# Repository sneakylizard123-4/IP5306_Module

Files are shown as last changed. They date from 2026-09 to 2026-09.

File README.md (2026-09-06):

# IP5306 Power-Bank Module

A small USB power bank module that uses a 1S lithium battery and outputs a regulated 5V supply.

This board is a small power bank module built around the Injoinic IP5306 SoC. It takes USB-C input to charge a lithium battery and outputs a regulated 5V rail from a USB-A port in output mode. It is a standalone module with no MCU, only a power button and 4-LED charge/fuel gauge handle all user input. I built it to have a fully integrated power path solution that avoids the complexity of discrete charger and boost circuits.

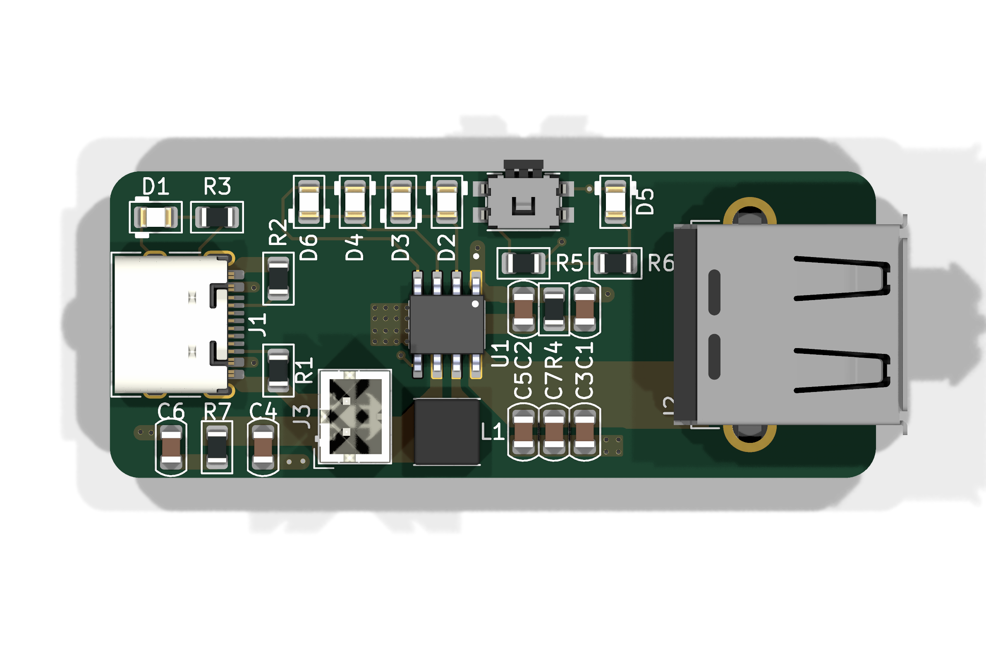
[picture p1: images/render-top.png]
3D model render


## Features

- IP5306: fully integrated 2.1A charger and 2.4A discharger with built-in boost converter.
- USB-C input for charging, USB-A output for 5V output.
- 1S Li-ion/LiPo battery connection via JST PH 2-pin header.
- Power button for power on/off and battery gauge.
- 4-LED charge/fuel gauge.
- 1uH shielded inductor for the boost converter.

## How It Works

The IP5306 has an entire power path inside of it. On the input side, 5v from USB-C charges a connected 1S lithium battery through the IP5306's built-in 2.1A charger. On the output side, the chip boosts the battery voltage to a regulated 5V output rail when in power-bank mode. The boost inductor and output capacitors form the boost converter, while the battery, LED, and decoupling capacitors support the charge path, gauge, and IC supply. Pressing the KEY button powers the module on/off and goes through the fuel gauge.

| Block | Part | Role |
|---|---|---|
| Power | IP5306 | Power Bank SoC with battery charger, boost regulator, 5V rail, charge gauge |
| Input | HRO TYPE-C-31-M-12 | USB-C receptacle for charging input |
| Output | Connfly DS1095 | USB-A receptacle for 5V power-bank output |
| Battery | B2B-PH-K | JST PH 2-pin connector to 1S Li-ion/LiPo battery |
| Inductor | Coilcraft XFL4020-102MEC | 1uH boost converter inductor |
| Capacitors | 10uF x4, 22uF x3  Boost output + IC decoupling |
| Resistors | 5.1k x2, 10k x3, 2 ohm x2 | USB-C CC pulldowns, biasing, LED current limit |
| LEDs | 0805 x6 | Charge and boost status indicators |
| Button | Panasonic EVQPUM | Power on/off + fuel gauge on KEY pin |

### Power Tree

The power path flows from the USB-C input through the IP5306 charger into the battery, and from the battery through the IP5306 boost converter out to the USB-A port. The KEY button and LED gauge hang off the chip's control pins.

| Direction | Path |
|---|---|
| Charge | USB-C (5V) -> IP5306 charger -> 1S battery |
| Discharge | 1S battery -> IP5306 boost -> 5V USB-A out |

## Board

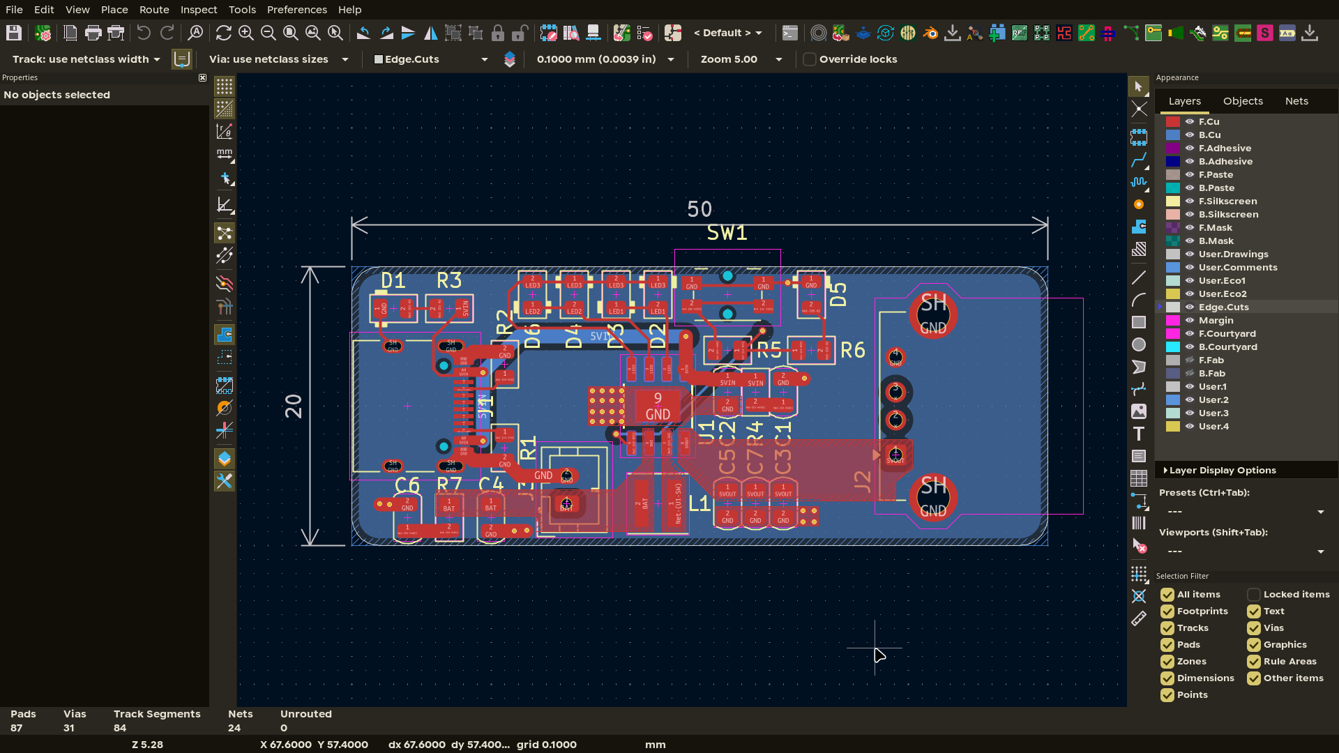
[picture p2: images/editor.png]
IP5306 module open in the KiCad PCB editor


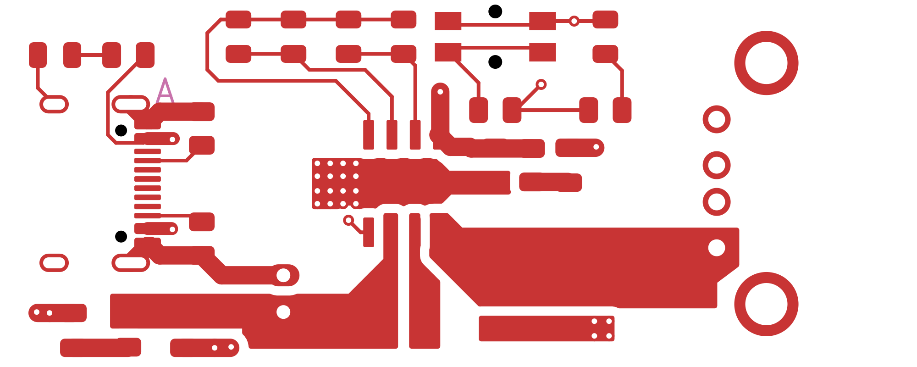
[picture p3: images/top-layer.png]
Top copper layer

*Top layer with the tracks, pads and ground pour.*

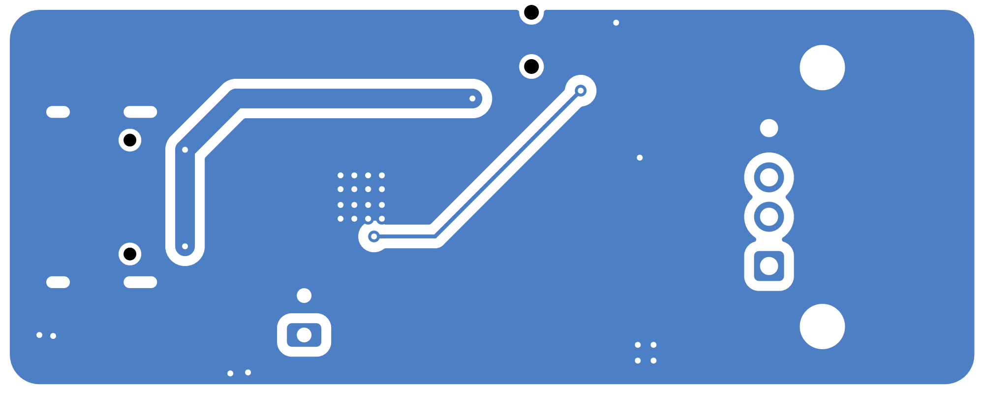
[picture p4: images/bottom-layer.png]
Bottom copper layer

*Bottom layer with the stitched ground return path.*

Assembled board, top view

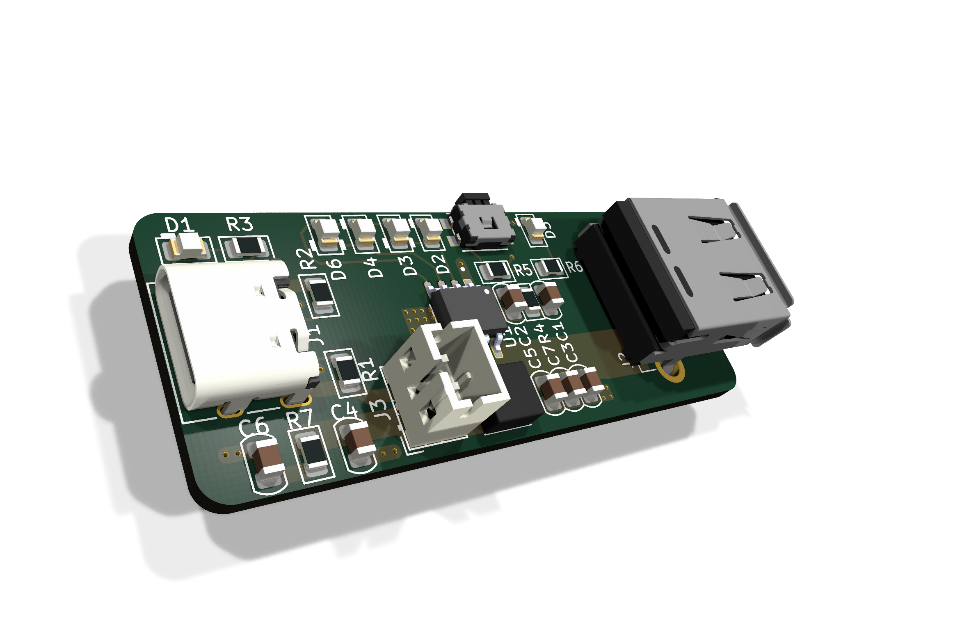
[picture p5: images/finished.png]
Assembled board, isometric view


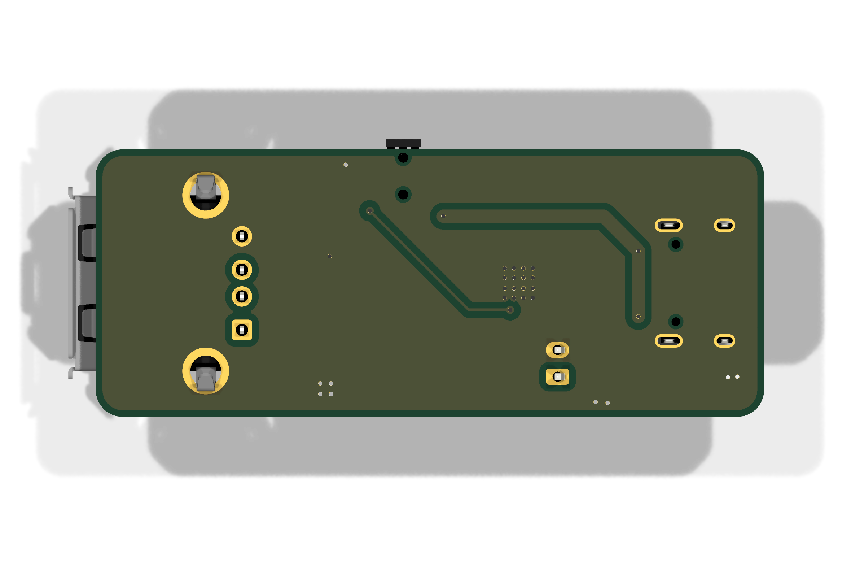
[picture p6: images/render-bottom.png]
Assembled board, bottom view


## Usage

1. Connect a 3.7V Li-ion/LiPo battery to the JST PH connector. 
2. Connect the USB-C to charge the battery. the LEDs indicate charge state. 
3. Connect a device to the USB-A port and press the power button to enable the 5V output; short presses cycle the LED fuel gauge and a long press toggles the module on/off.

| Pin | Function |
|-----|---|
| BAT+ / BAT- | JST PH battery connections (1S Li-ion/LiPo) |
| KEY | Power button input |
| GND | Common ground |

## Repository Structure

```
├── kicad/            # PCB source files
│   └── production/   # Gerbers + drill files
├── cad/              # .step export + native CAD source
├── firmware/         # Firmware source code
├── images/           # Renders, PCB screenshots, build photos
├── BOM.csv           # Bill of materials w/ links + total cost line
└── JOURNAL.md        # Work journal
```

## Cost

| Item | Cost |
|---|---|
| PCB | $3.20 |
| Shipping | $1.50 |
| **PCB subtotal** | **$4.70** |
| Components | $12.99 |
| **Total** | **$17.69** |

*Full BOM available in BOM.csv*

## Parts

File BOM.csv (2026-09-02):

Ref | Value | LCSC# | MPN | Manufacturer | Footprint | Qty | Unit Price($) | Ext Price($) | Supplier Link
C1 | C2 | C4 | C6 | 10uF 25V X5R | C15850 | CL21A106KAYNNNE | Samsung Electro-Mechanics | 0805 | 20 | 0.0871 | 1.74 | https://www.lcsc.com/product-detail/C15850.html
C3 | C5 | C7 | 22uF 25V X5R | C86816 | GRM21BR61E226ME44L | muRata | 0805 | 10 | 0.0698 | 0.70 | https://www.lcsc.com/product-detail/C86816.html
D1 | D2 | D3 | D4 | D5 | D6 | Orange LED 0805 | C965813 | XL-2012UOC | XINGLIGHT | 0805 | 50 | 0.0096 | 0.48 | https://www.lcsc.com/product-detail/C965813.html
J1 | USB-C Receptacle 16P | C165948 | TYPE-C-31-M-12 | Korean Hroparts Elec | SMD | 5 | 0.1724 | 0.86 | https://www.lcsc.com/product-detail/C165948.html
J2 | USB-A Right Angle | C19944603 | DS1095-WNR0 | CONNFLY Elec | Through Hole | 5 | 0.2076 | 1.04 | https://www.lcsc.com/product-detail/C19944603.html
J3 | JST PH 2P 2mm | C131337 | B2B-PH-K-S(LF)(SN) | JST | Through Hole | 20 | 0.0356 | 0.71 | https://www.lcsc.com/product-detail/C131337.html
L1 | 1uH Shielded Inductor | C5355380 | XFL4020-102MEC | Coilcraft | SMD 4x4mm | 1 | 2.5134 | 2.51 | https://www.lcsc.com/product-detail/C5355380.html
R1 | R2 | 5.1k 1% 0805 | C27834 | 0805W8F5101T5E | UNI-ROYAL | 0805 | 100 | 0.0065 | 0.65 | https://www.lcsc.com/product-detail/C27834.html
R3 | R5 | R6 | 10k 1% 0805 | C2907219 | FRC0805F1002TS | FOJAN | 0805 | 100 | 0.0035 | 0.35 | https://www.lcsc.com/product-detail/C2907219.html
R4 | R7 | 2R 1% 0805 | C114246 | RC0805FR-072RL | YAGEO | 0805 | 50 | 0.0261 | 1.31 | https://www.lcsc.com/product-detail/C114246.html
SW1 | Tactile Switch 4.7x4.5mm | C388885 | EVQPUD02K | PANASONIC | SMD | 5 | 0.2299 | 1.15 | https://www.lcsc.com/product-detail/C388885.html
U1 | IP5306 ESOP-8 | C181692 | IP5306 | INJOINIC | ESOP-8 | 5 | 0.2989 | 1.49 | https://www.lcsc.com/product-detail/C181692.html
PCB | Bare PCB 5 pcs (JLCPCB special offer) |  |  | JLCPCB |  | 5 | 0.64 | 3.20
Shipping |  | Global Standard (JLCPCB) |  |  |  | 1 | 1.50 | 1.50
Total |  |  | Components (LCSC) + PCB + shipping |  |  |  | 17.69

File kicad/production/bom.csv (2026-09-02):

Designator | Footprint | Quantity | Value | LCSC Part #
C1, C2, C4, C6 | 0805 | 4 | 10uF
C3, C5, C7 | 0805 | 3 | 22uF
D1, D2, D3, D4, D5, D6 | 0805 | 6 | LED
J1 | USB_C_Receptacle_HRO_TYPE-C-31-M-12 | 1 | USB_C_Receptacle_USB2.0_16P
J2 | USB_A_Connfly_DS1095 | 1 | USB_A
J3 | JST_PH_B2B-PH-K_1x02_P2.00mm_Vertical | 1 | Conn_01x02
L1 | L_Coilcraft_XxL4020 | 1 | 1uH XFL4020-102MEC
R1, R2 | 0805 | 2 | 5.1k
R3, R5, R6 | 0805 | 3 | 10k
R4, R7 | 0805 | 2 | 2
SW1 | Panasonic_EVQPUM_EVQPUD | 1 | SW_Push
U1 | SOP127P600X165-9N | 1 | IP5306

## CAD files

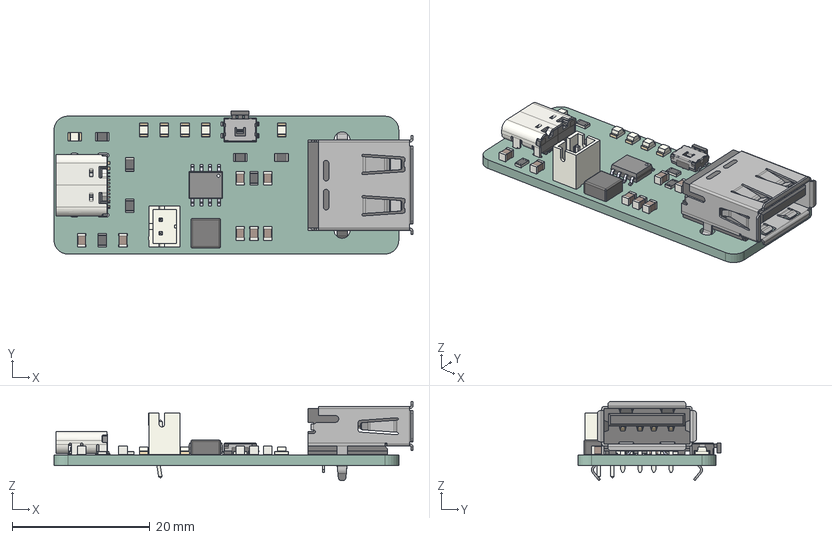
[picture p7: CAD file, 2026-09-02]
cad/IP5306_Module.step
52.1 x 20.8 x 11.5 mm
R_0805_2012Metric x 7
C_0805_2012Metric x 7
USB_A_Molex_67643_Horizontal
LED_0805_2012Metric x 6
L_Coilcraft_XAL4020-XXX
IP5306
JST_B2B_PH_K
Panasonic_EVQPUM_EVQPUD
USB_C_Receptacle_16P_TopMnt_Horizontal_GCT_USB4105-xx-A
IP5306_Module_PCB

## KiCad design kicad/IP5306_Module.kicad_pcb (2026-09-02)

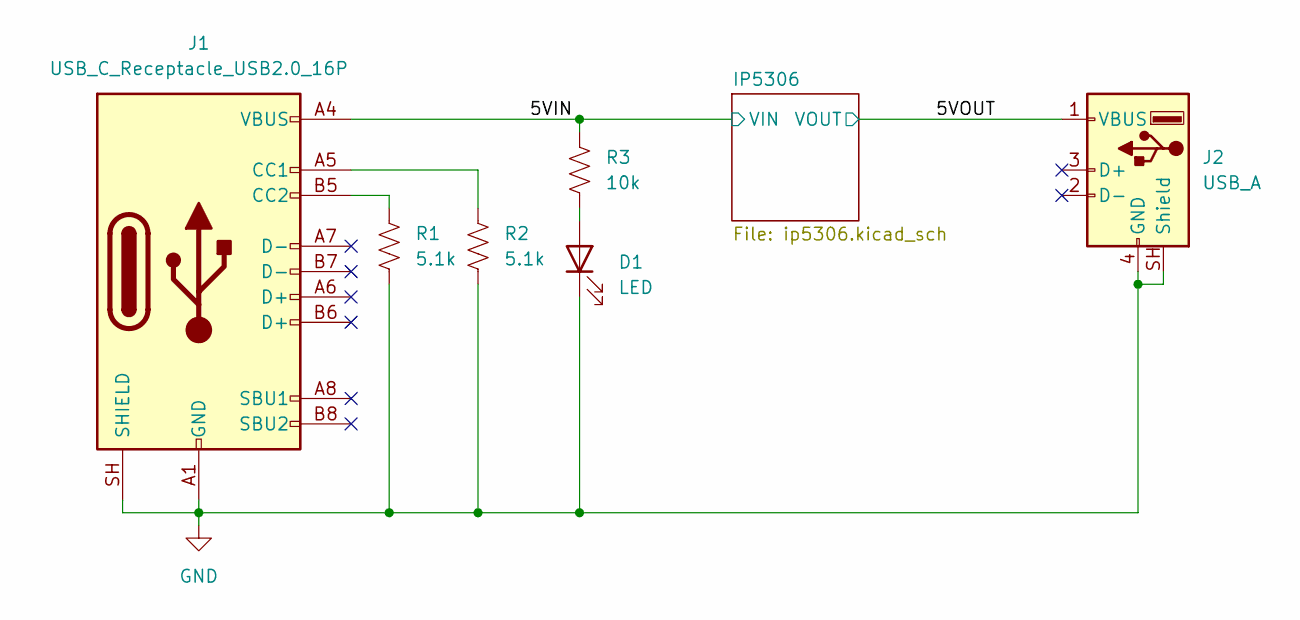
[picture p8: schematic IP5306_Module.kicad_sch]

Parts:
D1: LED; LED_0805_2012Metric
J1: USB_C_Receptacle_USB2.0_16P; USB_C_Receptacle_HRO_TYPE-C-31-M-12
J2: USB_A; USB_A_Connfly_DS1095
R1, R2: 5.1k; R_0805_2012Metric
R3: 10k; R_0805_2012Metric

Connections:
/5VIN: J1.A4 (VBUS), J1.A9 (VBUS), J1.B4 (VBUS), J1.B9 (VBUS), R3.1; also elsewhere on the board
/5VOUT: J2.1 (VBUS); also elsewhere on the board
GND: D1.1 (K), J1.A1 (GND), J1.A12 (GND), J1.B1 (GND), J1.B12 (GND), J1.SH (SHIELD), J2.4 (GND), J2.SH (Shield), R1.2, R2.2; also elsewhere on the board
unnamed: D1.2 (A), R3.2
unnamed: J1.A5 (CC1), R2.1
unnamed: J1.B5 (CC2), R1.1

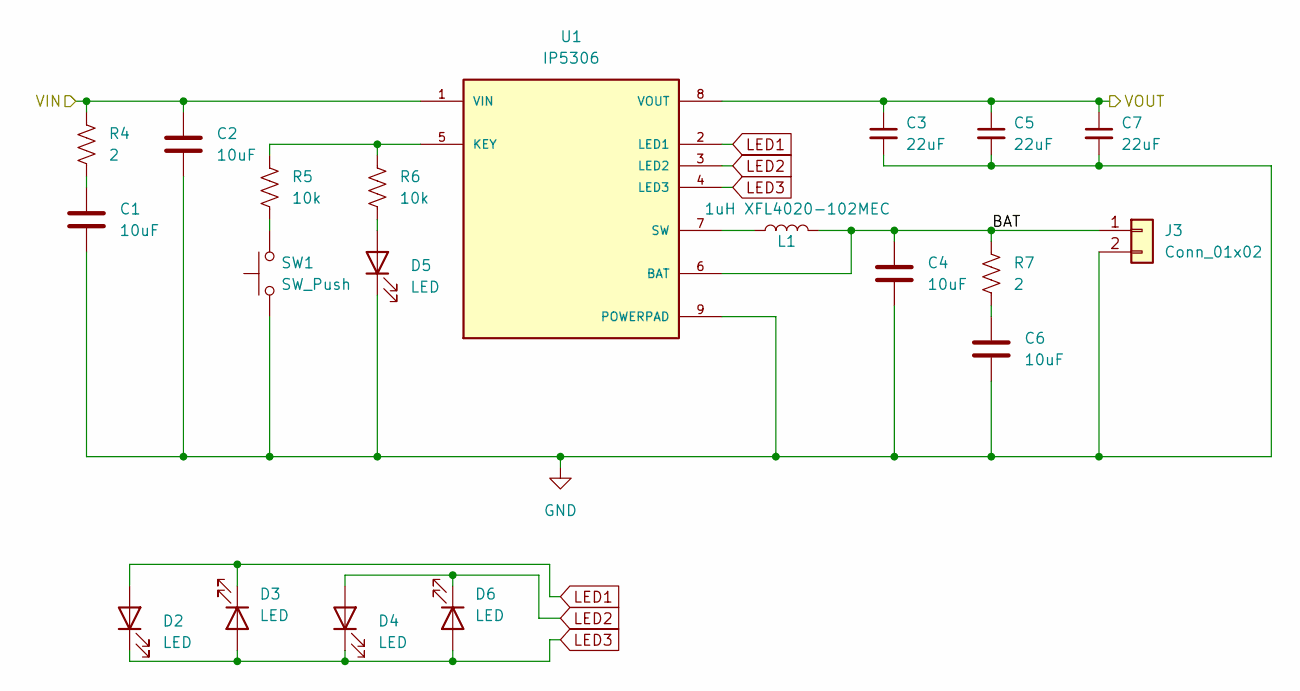
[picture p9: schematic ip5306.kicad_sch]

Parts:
C1, C2, C4, C6: 10uF; C_0805_2012Metric
C3, C5, C7: 22uF; C_0805_2012Metric
D2, D3, D4, D5, D6: LED; LED_0805_2012Metric
J3: Conn_01x02; JST_PH_B2B-PH-K_1x02_P2.00mm_Vertical
L1: 1uH XFL4020-102MEC; L_Coilcraft_XxL4020
R4, R7: 2; R_0805_2012Metric
R5, R6: 10k; R_0805_2012Metric
SW1: SW_Push; Panasonic_EVQPUM_EVQPUD
U1: IP5306; SOP127P600X165-9N; PARTREV 1.31

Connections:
/5VIN: C2.1, R4.1, U1.1 (VIN); also elsewhere on the board
/5VOUT: C3.1, C5.1, C7.1, U1.8 (VOUT); also elsewhere on the board
/IP5306/BAT: C4.1, J3.1, L1.2, R7.1, U1.6 (BAT)
GND: C1.2, C2.2, C3.2, C4.2, C5.2, C6.2, C7.2, D5.1 (K), J3.2, SW1.1, U1.9 (POWERPAD); also elsewhere on the board
LED1: D2.2 (A), D3.1 (K), U1.2 (LED1)
LED2: D4.2 (A), D6.1 (K), U1.3 (LED2)
LED3: D2.1 (K), D3.2 (A), D4.1 (K), D6.2 (A), U1.4 (LED3)
unnamed: C1.1, R4.2
unnamed: C6.1, R7.2
unnamed: D5.2 (A), R6.2
unnamed: R5.2, SW1.2
unnamed: R5.1, R6.1, U1.5 (KEY)
unnamed: L1.1, U1.7 (SW)

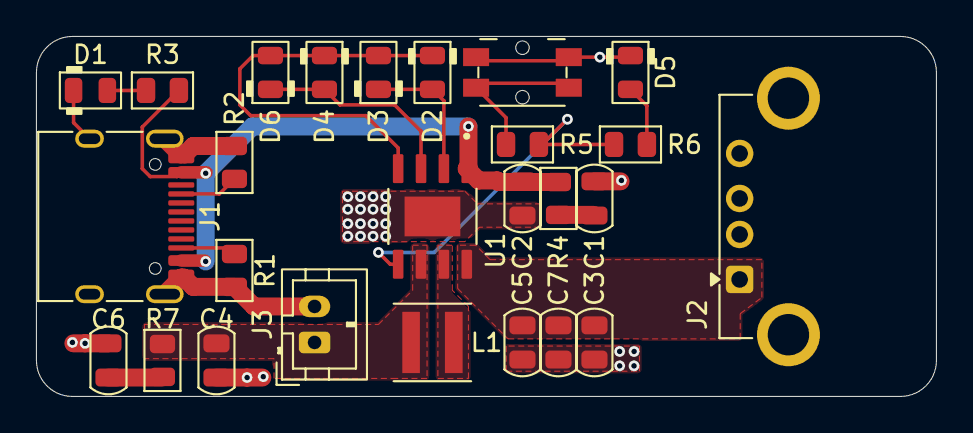
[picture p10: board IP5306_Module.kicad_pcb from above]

Board: 2 copper layers, 50.0 x 20.0 mm, 26 parts (0 on the bottom side), 16 nets.

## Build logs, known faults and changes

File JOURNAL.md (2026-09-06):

---
title: IP5306 Module
author: sneak
description: A super small 2-layer module that uses the IP5306 SoC, with USB-C charging input, USB-A 5V output, a battery connector, and LED indicators.
created_at: 2026-09-02
---

# 2026-09-02: Schematic capture

Started by pulling up the IP5306 datasheet. This little SoC does everything in one chip - it charges the lithium cell, boosts it back up to 5V for output, and even has its own LEDs for capacity and charging state, and those same led pins can also be used for I2C in some variants.

The core parts of the schematic were the IP5306 itself, a USB-C jack for input (charging), a USB-A jack for the 5V output, a JST connector for the battery, some LEDs, and the passives around the power path. I mainly copied the reference circuit from the datasheet, mostly because I trust it more than my own guesses for a power chip like this.

Biggest miss here: I did not connect the USB-C data pins (D+/D-) to anything, just left them floating with the CC pins handled via breakouts. The IP5306 is a dedicated power device, so it does not need data, but leaving them unconnected on the connector is a bit sloppy and I know some host chargers look for something there.

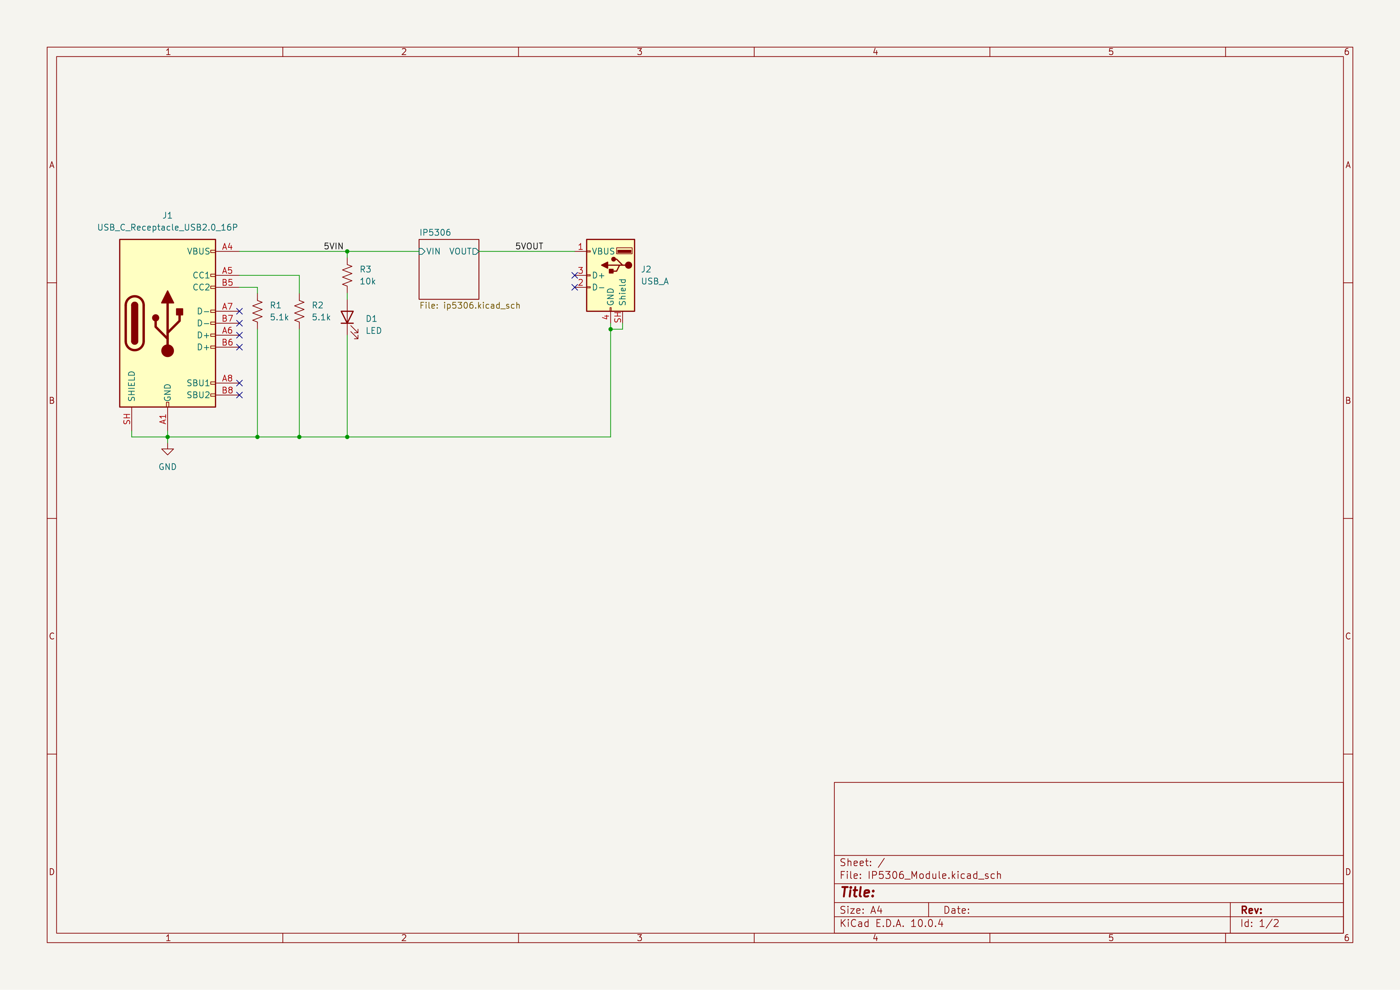
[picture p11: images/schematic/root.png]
schematic


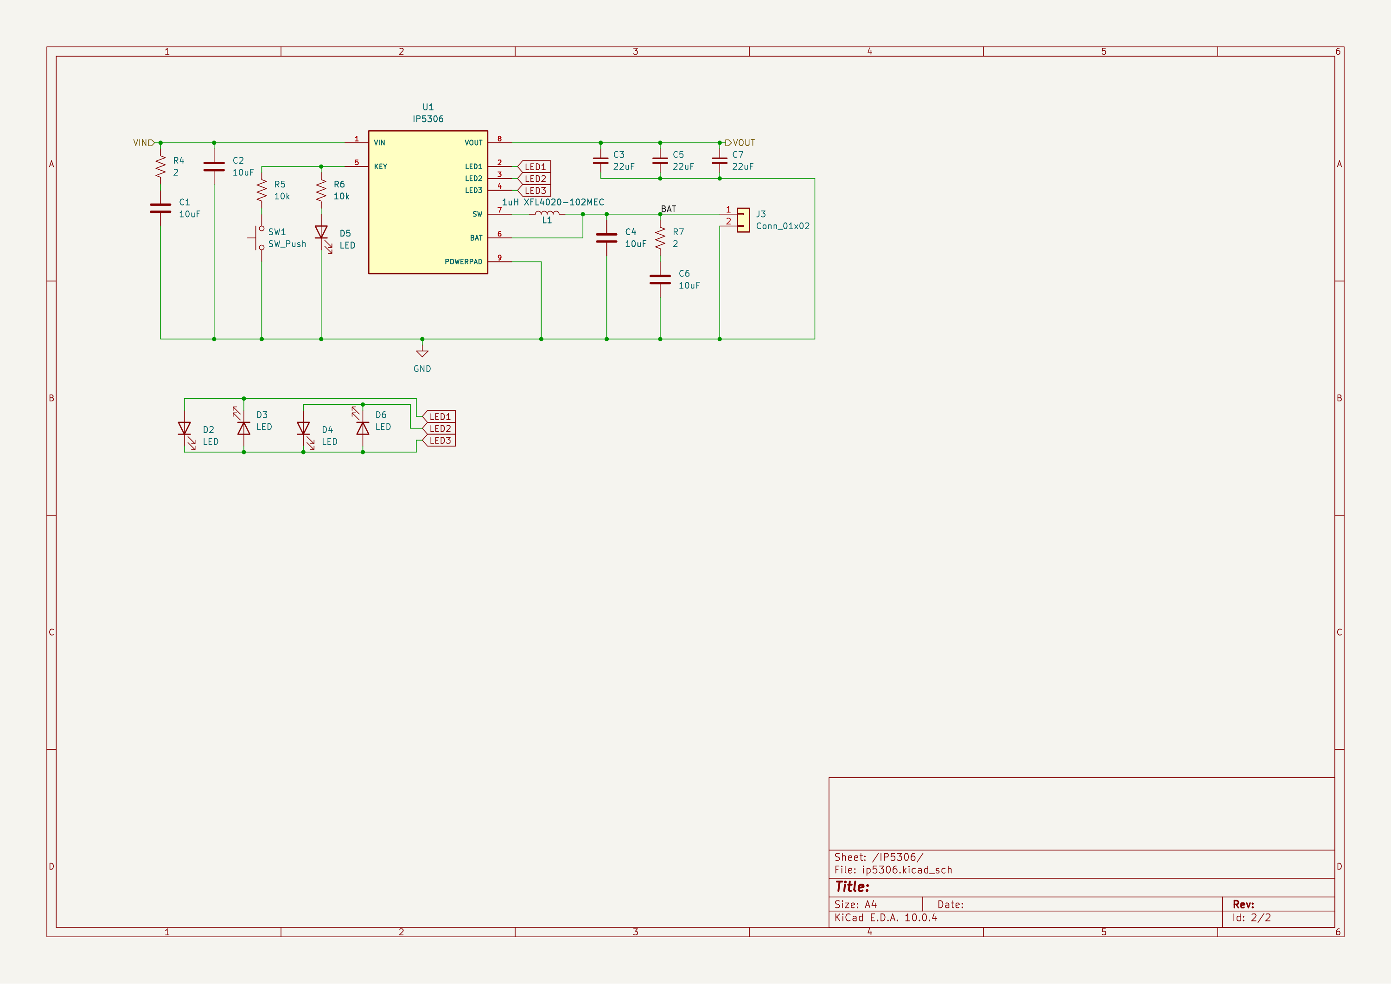
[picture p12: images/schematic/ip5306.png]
IP5306 sub-sheet


**Total time spent: 3 hours**

# 2026-09-02: Layout and routing

Layout was the part that took most of the session. The board is two layers (finally a sub-4 layer board) and I wanted it small, so I ran everything tight. I placed the IP5306 in the middle, USB-C on one edge and USB-A on the other, with the battery connector off to the side.

I put copper pours on both the top and bottom faces to act as a solid ground and to help handle the current on the 5V output path. The boost converter pulls bursts of current, so a thin track would have been a voltage droop problem. I also dropped vias around the pours to stitch the ground planes together across both layers, so there are no dead zones under the IC where return current would have to loop around.

I originally routed the battery traces right under the IP5306's inductor. The datasheet explicitly says to keep the switching node and inductor area clean, so I reworked it and moved the battery connector so its tracks bypass that zone.

board in PCB editor

top layer
bottom layer

**Total time spent: 4 hours**

# 2026-09-02: Finishing touches and gerbers

The module is almost done, so today was about closing it out. I went back through and double checked the footprints against the real parts. Getting a footprint wrong is the kind of mistake that shows up when the board arrives.

I also had to clean up my silkscreen because a bunch of reference designators were sitting on top of copper pours and would have been half-etched away. Moved the critical labels like the battery polarity so nothing confusing is printed over where a pin actually is.

Then I ran the fabrication toolkit and generated the gerbers and the drill files and zipped them up in the project folder. Still nervous about the USB data pins being left unconnected, but for a bench power bank I think it is fine. Next round I would wire D+ and D- properly. If i need i can connect them directly through a solder blob.

finished board

**Total time spent: 2 hours**

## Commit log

2026-09-02 cad, gitignore, journal, readme
    [IP5306_Module.kicad_pcb, IP5306_Module.step, bom.csv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]
2026-09-02 start bom
2026-09-02 bom and readme
    [BOM.csv, export_cart_20260903_063642.csv]
